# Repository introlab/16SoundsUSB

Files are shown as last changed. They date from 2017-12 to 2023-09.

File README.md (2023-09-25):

## 16SoundsUSB - 16 Synchronized Inputs USB (UAC2) Sound Card. 

## Authors
* Vincent-Philippe Rhéaume
* Dominic Létourneau
* Cédric Godin

We designed this sound card to work with our [ODAS](https://github.com/introlab/odas) sound source localization, tracking and separation library. You can also have a look at the [ODAS GUI](https://github.com/introlab/odas_web/) application. 

## 
* Please contact us if you need an already assembled [16SoundsUSB kit](https://github.com/introlab/16SoundsUSB/wiki/Kits).

## Latest Release
* [16SoundsUSB REV 1.0](https://github.com/introlab/16SoundsUSB/releases/tag/rev1.0)
  * [16SoundsUSB_Schematic](https://github.com/introlab/16SoundsUSB/releases/download/rev1.0/16SoundsUSB_Schematic_REV_1_0.PDF)
  * [16SoundsUSB_PCB_Fab_Assembly](https://github.com/introlab/16SoundsUSB/releases/download/rev1.0/16SoundsUSB_PCB_Fab_Assembly_REV_1_0.zip)

## Features

* 16 Synchronized Differential Inputs :
  * 2 x Cirrus Logic CS5368 high quality ADC (16 channels) 
* 4 Synchronized Single Ended Outputs :
  * Cirrus Logic CS4384 high quality DAC (4/8 channels used)
  * 2 Analog stereo outputs - 3.5 mm jack output format, 600Ω source impedance 
* Low-Jitter Master Clock :
  * Cirrus Logic CS2100 clock generator and clock multiplier/jitter-reduced clock frequency synthesizer 
* XTAG programming port
* Expansion header :
  * I2C-SDA, I2C-SCL, GPIO, GND, 5.6V (output of boost switching pre-regulator)
* Supported Sampling Rates :
  * 8kHz, 11.025kHz, 16kHz, 22.050kHz, 32kHz, 44.1 kHz, 48 kHz, 88.2kHz, 96 kHz
* Power :
  * USB Powered or
  * External 5V power supply
  * Measured current draw at 5V input for standard firmware: 600mA
* Supported Operating Systems :
  * Mac OSX, Linux, Windows 10 (UAC2 not working yet)
* Hand assembly is possible :
  * Mostly TQFP, SOIC packages on-board. Solder paste and heat gun recommended for 2 DFN-6 packages. 

## Pictures

16SoundsUSB Top
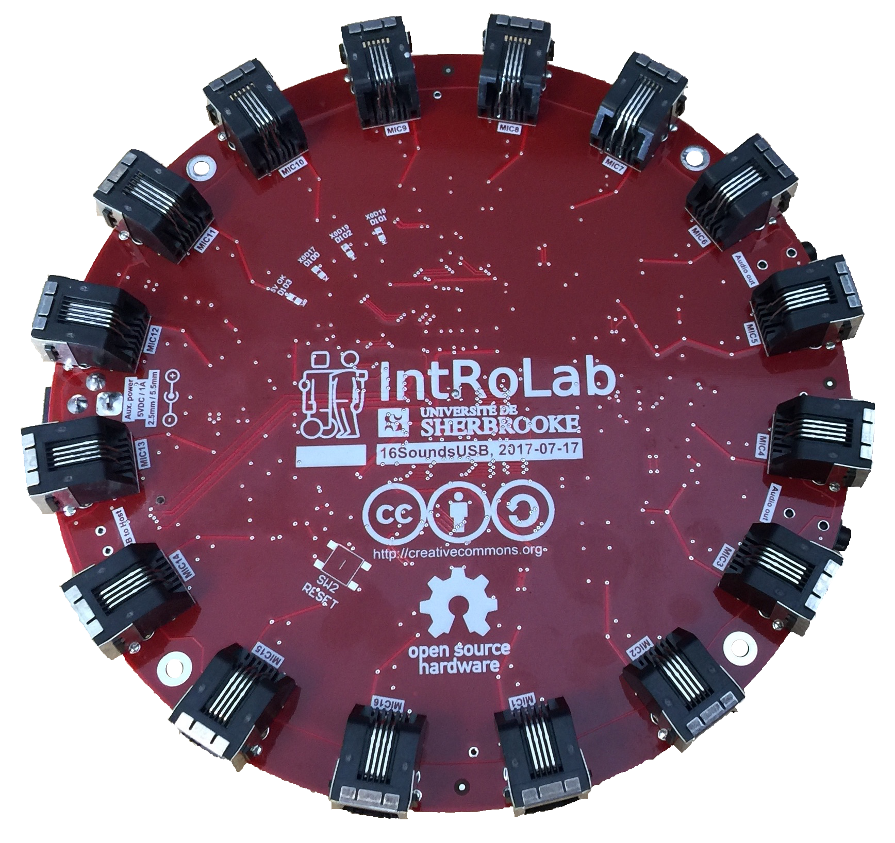
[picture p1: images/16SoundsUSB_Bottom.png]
16SoundsUSB Bottom


## Regulatory Compliance
Please read the [Regulatory Compliance Wiki Page](https://github.com/introlab/16SoundsUSB/wiki/Regulatory-Compliance).

## License

[Creative Commons Attribution Share Alike 4.0](https://github.com/introlab/16SoundsUSB/blob/master/LICENSE.txt)

## Microphones

[Compatible Electret and MEMS microphones](https://github.com/introlab/xSoundsMicrophones)

## Acknowledgements
The design is based on the [XMOS xCORE-200 Multichannel Audio Platform](https://www.xmos.com/support/boards?product=18334). This project is supported by [IntRoLab - Intelligent / Interactive / Integrated / Interdisciplinary Robot Lab](https://introlab.3it.usherbrooke.ca/), Sherbrooke, Québec, Canada.

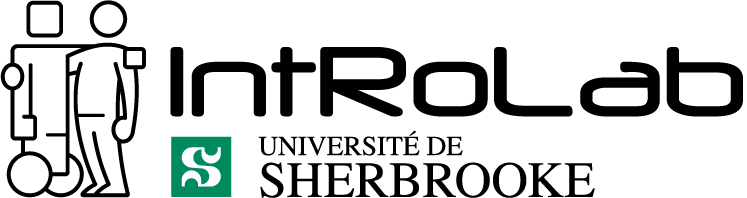
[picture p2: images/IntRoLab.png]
IntRoLab


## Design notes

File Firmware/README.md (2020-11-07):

# Flashing the firmware

## OSX

1. Load environment variables (your xTIMEcomposer version may vary)
* source /Applications/XMOS_xTIMEcomposer_Community_14.2.3/SetEnv.sh

2. Flash with xflash (your xTIMEcomposer version may vary)
* /Applications/XMOS_xTIMEcomposer_Community_14.2.3/bin/xflash <Firmware .xe file>

# Building the firmware

[You can get the code by agreeing to the licence on the XMOS site](https://www.xmos.ai/download/sw_usb_audio-[sw](6.15.2).zip) and make few changes to the sw_usb_audio-[sw]_6.15.2 reference firmware. Diff files from version 6.15.2 are provided in the [app_usb_aud_xk_216_mc](app_usb_aud_xk_216_mc) directory for your convenience. Sample rate support from 16kHz to 96kHz is included in the patch.

# Regulatory Compliance

Université de Sherbrooke provides 16SoundsUSB development board under the following conditions:

* 16SoundsUSB is intended for use for ENGINEERING DEVELOPMENT, DEMONSTRATION, OR EVALUATION PURPOSES ONLY and is not considered by Université de Sherbrooke to be a finished end-product fit for general consumer use.
* The 16SoundsUSB board generates, uses, and can radiate radio frequency energy and has not been tested for compliance with the limits of computing devices pursuant to part 15 of FCC rules, which are designed to provide reasonable protection against radio frequency interference. Operation of this equipment in other environments may cause interference with radio communications, in which case the user at his own expense will be required to take whatever measures may be required to correct this interference.
* Persons handling the product(s) must have electronics training and observe good engineering practice standards. As such, the goods being provided are not intended to be complete in terms of required design-,marketing-, and/or manufacturing-related protective considerations, including product safety and environmental measures typically found in end products that incorporate such semiconductor components or circuit boards. This evaluation board/kit does not fall within the scope of the European Union directives regarding electromagnetic compatibility, restricted substances (RoHS), recycling (WEEE), FCC, CE or UL, and therefore may not meet the technical requirements of these directives or other related directives.
* The user assumes all responsibility and liability for proper and safe handling of the goods. Further, the user indemnifies Université de Sherbrooke from all claims arising from the handling or use of the goods. Due to the open construction of the product, it is the user’s responsibility to take any and all appropriate precautions with regard to electrostatic discharge. NEITHER PARTY SHALL BE LIABLE TO THE OTHER FOR ANY INDIRECT, SPECIAL, INCIDENTAL, OR CONSEQUENTIAL DAMAGES. Université de Sherbrooke currently deals with a variety of customers for products, and therefore our arrangement with the user is not exclusive.
* Université de Sherbrooke assumes no liability for applications assistance, customer product design, software performance, or infringement of patents or services described herein.

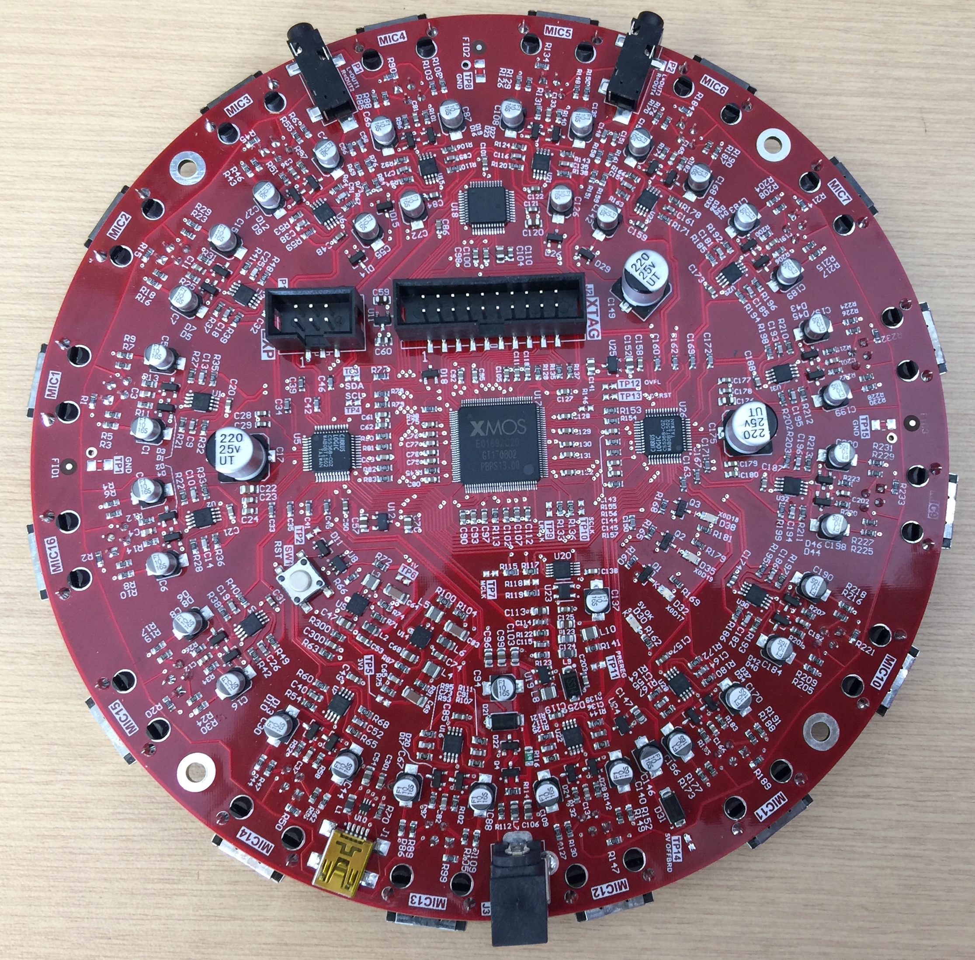
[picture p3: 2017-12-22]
images/16SoundsUSB_Top.jpg

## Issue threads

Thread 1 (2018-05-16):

Where can I purchase one of 16SoundsUSB?

jamesshao8, 2018-05-16:
This is probably rather an enquiry than an issue. I recently tried odas/odas_web with respeaker mic array v1.0 and v2.0. I am quite impressed by your project.

I want to improve the angle of separation, so that I can distinguish 2 sources in closer angles. I believe this 16 array would produce better result. So could you direct me some place that I can buy this 16 channel device?

Thanks.

doumdi, 2018-06-05:
Please email Prof. [François Michaud](mailto:francois.michaud@usherbrooke.ca) for a quote.

Thanks!

Closed 2018-07-16.

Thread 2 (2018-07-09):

microphone RJ45

jamesshao8, 2018-07-09:
Hello there,

I made one of this 16SoundsUSB according to your design files. I found there is actually no microphone on board, instead there are 16 RJ45 sockets.

According to the schematics, there are already on board input amplifiers, so what I need is some analog microphone units, and connect their outputs to each RJ45 port 2 and 4, right?

Do you have some suggestion about the microphone model/brand?

Thank you!

Regards,
Shao

qinyunchuan, 2018-07-15:
I think you should attach a ECM to the RJ45 connector.

jamesshao8, 2018-07-15:
It's actually RJ11, I found the design file of MIC-RJ11 board from 8SoundsUSB project. I think they can be used in this 16SoundsUSB project as well. So I am trying to make them locally.  Right now the I am working on how to download firmware to this board. What is ECM anyway? A type of microphone? I do have plan to customize the MIC board with better microphone for higher sensitivity.

doumdi, 2018-07-16:
Please have a look at the microphone design here : https://github.com/introlab/xSoundsMicrophones. We have electret design and MEMS design available.

doumdi, 2018-07-16:
Please note :  We use RJ11 connectors and cables in a custom configuration, allowing differential signals and power supply to our own microphone design. It is not compatible with any external 3.5mm adapter and microphone. We made this choice to make the system robust to noise, compact and easy to install. Everything is powered by the sound card, using USB 2.0.

jamesshao8, 2018-07-16:
Nice! Will take a look at these microphone designs.

jamesshao8, 2018-08-09:
Sorry, I was wrong about the sensitivity, mems with -38dB sensitivity should be better than the electret one with -44dB sensitivity. But which pre-amplification is better is still unknown to me. On electret design I have measured the real max gain is 20 times. Will try the mems one. I might also put those amplifiers in series and see how they work together.

vrheaume, 2018-08-09:
Hello James,

Our MEMS microphone board design is more recent and was designed to go along with our 16SoundsUSB. The electret microphone board design dates back to when the 8SoundsUSB was designed.

The gain values for both microphones were set in a very subjective / arbitrary manner. We had 2 concerns: we don't want too much gain to saturate the signal chain, yet we want enough gain to be able to hear properly when speaking from a few meters away.

Overall, we like the new microphones better with the 16SoundsUSB than we liked the older microphones with the 8SoundsUSB. However, we haven't done apples-to-apples comparison on the two microphone designs.

The MEMS microphone has better sensitivity (by 6dB) and better SNR (by 2-4dB), according to its specification (but I'm not sure we can really compare the specs since they're from different manufacturers, thus maybe different test conditions). We also experienced much, much less signal degradation coming from electromagnetic interference with the MEMS microphone (which we noticed recently when using the electret microphones a few inches away from a wifi router). The VM1000 MEMS microphone is supposedly waterproof and dustproof, features we haven't explored in-depth yet.

It is possible to change one resistor to adjust the gain on the electret microphone board, should you find it desirable. Let me know if you need help with this.

jamesshao8, 2018-08-10:
Thank your for your explanation.

I will try to make the mems one locally and compare them with the electret one. I noticed in the mems design R7/R6=10 is the gain, and I replaced R7 to 100k resistor, hoping to get higher gain. I have also bought some mics from knowles. One of them has -18dB sensitivity and 63dB SNR, another one has -40dB sensitivity and 70dB SNR. I am worried about saturating the ADC as well, so I am not sure choosing a mic with higher sensitivity or using higher gain in amplifier would guarantee I can hear sounds for longer distance, but I think higher SNR is always better.

vrheaume, 2018-08-10:
In case you haven't noticed, you should be aware that soldering the MEMS microphone is not trivial. The trick I use is to put solder on the PCB pads, then place the microphone with the tweezers, then use the hot air gun to reflow the solder. The MEMS microphone will self-align with the pads as the solder reflows, and then I give it a small push downward with the tweezer to make sure it is flat against the board.

If you go intend to increase the gain, you might want to make sure the opamp's gain-bandwidth specification is respected...

Keep us updated with the results of your experimenting!

jamesshao8, 2018-08-10:
We have a partnership with a local PCB/SMT factory. We usually ask them to do small volume prototyping. I think they are able to solder this mems microphones. But for knowles mics, I will have to solder them by myself, connecting them with some wires, so that I can put into my bread board and do the experiments.

We would love to contribute to this interesting project. So sure we will update our result.

jamesshao8, 2018-08-25:
Hello @vrheaume,

I have tried the mems mics these days. They are receiving sound in longer distance than electret ones indeed. And my own modification of the resistor increased the distance even further. But the distance is still not enough for me. And in long distance, I can't see obvious beamforming effect as I can in short distance.

Also I am wondering why a basic op-amp is used in the mems design instead of a specialized audio amplification chip in the electret? If I some how connect the mems mic to the amplification chip in electret design, will the distance be even longer? Thanks.

vrheaume, 2018-08-25:
Hello @jamesshao8,

Regarding the microphone distance: I have no precise recommendation for this, but here are a few thoughts:

- Perhaps you could get a few dB of gain with enclosure design.
- What is the maximum gain you experimented with? Perhaps we could try with higher gain still. Perhaps this would require another amplifier due to gain-bandwidth product limitation, perhaps it would require modifications on the microphone PCB design.
- Are you getting clean signals when you amplify more? Does it start getting noisy? If so perhaps we could find a lower-noise opamp (would cost a little bit more; perhaps something like the [OPA1662](http://www.ti.com/lit/ds/symlink/opa1662.pdf)).
- Perhaps we could shop around specifically for microphones that are intended by the manufacturer for "far-field use"; for example [this one](https://www.invensense.com/news-media/invensense-introduces-industrys-first-74-db-snr-analog-mems-microphone-enabling-far-field-audio-capture/).

Regarding the choice of using an opamp instead of the TS472 amplifier: I chose to do it this way because, in general, I try to use parts which have several compatible alternatives, so that we avoid sourcing problems. The opamp package is standard, you can find drop-in replacements from several manufacturers, and models with different specs (power consumption, THD, gain-bandwidth product, etc), which isn't the case for the TS472.

I do not tend to think you'll see much difference by using the TS472 instead of the amplifier that's already on the MEMS microphone board. That would be an interesting thing to try out; let us know if you do.

vrheaume, 2018-09-05:
Yes, an enclosure/case _could_ help a little bit. I am no acoustics expert, it seems hard to tell how much improvement you could get, but I would think on the order of 1dB perhaps.

Regarding the electronic gain: you could go about 6-10dB more, with just a slightly better opamp (such as MCP6L92) and changing R7; going above this might require a new circuit with two stages of amplification.

However, when you increase the gain (either mechanically by enclosure design, or electronically), the tradeoff is that you'll get saturation faster. "No free lunch!"

Perhaps an AGC (automatic gain control) function (either fully-analog, or a programmable amplifier controlled by real-time processing firmware), in addition to the amplifier, should be considered. It would involve some hardware development however. Here's an [application note on the subject of AGC](http://www.onsemi.com/pub/Collateral/AN-6603.pdf.pdf).

jamesshao8, 2018-09-05:
Hello @vrheaume ,

I just tested the 16SoundsUSB and mems mic with my own modification at R7 in a silent lab (No reflection of sound, and no noise from outside the room). We found there is actually very little noise left on the sound sources figure ( which means there isn't much background noise from the circuit). We can hear clearly human voice from a distance of 8 meters. So I think the sensitivity of mic and gain of op-amp is enough. Our main problem is with the beamforming algorithm. Also if we could extend 16SoundsUSB to a 64 channel device, it should have narrower pattern with high gain. But we will always try with high SNR mic and better op-amp. Since the modification of the main boards is too hard for us.

doumdi, 2020-08-19:
@jamesshao8 @vrheaume. There is a limitation with USB2 with the number of channels we can transmit over endpoints. 16 in is close to the maximum @ 96kHz.

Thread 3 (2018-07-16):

Please tell us what you do with 16SoundsUSB

doumdi, 2018-07-16:
We are curious to know how and where you use the 16SoundsUSB device. Please let us know!

jamesshao8, 2018-07-16:
I am originally from the radio world. Always wanted to study DOA and beamforming algorithm which is used in smart antenna. But multi-channel radio equipment are usually very expensive and there aren't many existing projects to learn from. Recently I found respeaker v2.0 can be used with odas to do 3-dimensional DOA and even beamforming. Then I found this 16SoundsUSB hardware, which I think can provide better resolution since it has more channel.

I think combined with a camera, 16SoundsUSB and odas can be used as an acoustic camera. To see where sounds come from and identify them on real-time video. With beamforming in static mode, I can even choose which sound source I want to listen to, like a telescope for sound. But if put into practical use maybe I need to scale it up to 64 channel or 128 channel and use microphone with higher sensitivity. Will experiment with existing design first and maybe simply some tuning in parameters will do.

doumdi, 2018-07-17:
@jamesshao8, thanks for sharing this with us. The acoustic camera and "static" beamformer capabilities are on the TODO list for ODAS. Please contact @FrancoisGrondin for questions concerning those topics.

U0x0U, 2020-08-19:
Hi, I'm from a research institute in Taiwan, which is committed to sound-related research .
16SoundsUSB is awesome for microphone array, and we plan to make the circuit board first.
I would really appreciate it if you could kindly give us some advice and suggestions.

doumdi, 2020-08-19:
@U0x0U you can find all fab files here: https://github.com/introlab/16SoundsUSB/releases. I would suggest you register to XMOS to get the firmware first to make sure it fits your needs. Few modifications are needed but the design is based on the
[xCORE-200 multichannel audio platform](https://www.xmos.com/products/audio/kits). You will need to accept the license and download the sw_usb_audio-[sw]_6.15.2 firmware and use the app_usb_aud_xk_216_mc for starting.

blursj, 2020-11-04:
@doumdi Dear sir, I am debugging 16SoundUSB board made by myself, and would you please release your few modifications which are needed based on the xCORE-200 multichannel audio platform? I appreciate for your help. My email is: blursj@gmail.com

roboav8r, 2020-12-01:
@doumdi I plan on integrating the kit onto a mobile robot platform, then using it for real-time human-robot interaction & sound event recognition.

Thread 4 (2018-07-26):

Is 4-wire RJ11 cable NOT supported by the 16SoundsUSB?

TooSchoolForCool, 2018-07-26:
Hi there,

Our lab bought a 16SoundsUSB from your lab a few months ago.

But now, we are trying to replace the original cable with a shorter one since the original cable is too long.

We bought some RJ11 cables from Amazon, and [here](https://www.amazon.com/Telephone-Plugs-Conductor-inches-Silver/dp/B01LKLRGWW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) is the link. However, these Rj11 cables do not work at all...

I was wondering what kind of cable is support by the 16SoundsUSB, and where can I find some shorter alternative cables.

Looking for your response, and thanks in advance :).

PS: I also took a picture of our RJ11 cable and the original cable. The left one is the RJ11 bought from Amazon, and the right one is the original cable.

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

vrheaume, 2018-08-02:
Hello,

Two things:

1. The connector on the 16SoundsUSB card can physically connect both to 4-pin and 6-pin "RJ" connectors. If using 6-pin connector and cable, only the 4 center pins are actually used to carry signals. [Go to this website for additional information on RJ11 and RJ12](http://www.differencebetween.net/technology/difference-between-rj11-and-rj12/)

2. The problem you are experiencing with the Amazon-bought cable is probably that it is a "straight" cable instead of a "crossed" cable. In a straight cable, pin 1 goes to pin 1, 2 goes to 2, etc; in a crossed cable, pin 1 goes to pin 4, pin 2 goes to pin 3, etc. In our case, +5V is on pin 4 on the microphone whereas it is pin 1 on the sound card itself, so you need a crossed cable. [This is an example of a crossed cable you can buy](https://www.amazon.com/Kenable-RJ12-Cross-Cable-BLACK/dp/B0051FKFXQ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). The reason for deciding to use crossed cables instead of straight is lost in time.

You should be able to confirm that the cables you have in hand are straight (Amazon) and crossed (ours) either visually (looking at the wire colors at both ends of the cable) or with a multimeter. You could buy new cables, or buy your own [connectors](https://www.amazon.com/Monoprice-Round-Stranded-50-Piece-107315/dp/B005E2Y7JE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) and [crimp tool](https://www.amazon.com/TRENDnet-RJ-45-RJ-12-RJ-11-TC-CT68/dp/B0000AZK4G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), to recycle the cables you have in hand and allow you to make custom-length cables in the future.

I hope this helps you. Let me know if it does not. I will look over our documentation and add a note regarding the type of cable if it isn't clear already. I'm sorry you had this problem.

Vincent R

TooSchoolForCool, 2018-08-10:
Thank you so much, Vincent!!!

I double checked both sides of the wire, I then found out their difference. And yes, the original cable is "crossed", whereas the one I bought from Amazon is not.

Again, thank you so much :).

vrheaume, 2018-08-15:
I'm glad I could help you figure this out. Let us know if you have more questions!

(I'm closing this issue since it is resolved)

Closed 2018-08-15.

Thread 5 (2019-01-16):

I can not compile

Yarulik, 2019-01-16:
Hello dear!

Thank you for such an interesting project, I was pleased to collect it!)

I compiled 16SoundUSB, but I cannot compile the project by changing the files as described.
An unmodified example app_usb_aud_xk_216_mc is compiled.

Additional targets can be installed from the xTIMEcomposer Studio
using the "Install New Hardware ..." option.
xmake [1]: *** [.build_2i16o16xxxxx_tdm8 / src / extensions / gpio_access.c.pca.xml.decouple] Error 1
xmake: *** [analyze] Error 2

Can anyone share a compiled project or a binary that I could check. I am an enthusiast and learn programming.

Thank you in advance!

yarulik1986@gmail.com

doumdi, 2019-01-18:
Hello @Yarulik ,

Have you tried the procedure [here:](https://github.com/introlab/16SoundsUSB/tree/master/Firmware)
With the firmware available [here :](https://github.com/introlab/16SoundsUSB/releases)

If you try compiling from XMOS source, try removing the gpio part, it is not needed.

doumdi, 2019-01-18:
In our firmware everything in gpio_access.c is commented.

doumdi, 2019-01-18:
**1) Comment line in audiohw.xc**
//#include "gpio_access.h"

**2) Add those definitions **
```
//Modified
on tile[0] : out port p_gpio_reset = XS1_PORT_4E;
on tile[0] : out port p_gpio_leds = PORT_LEDS;

//Define the address of the codecs
#define CS5368_I2C_ADDR1      (0x4D)
#define CS5368_I2C_ADDR2      (0x4C)

//Also define write function  to both codecs
#define ADC_REGWRITE1(reg, val) {data[0] = val; i2c_shared_master_write_reg(r_i2c, CS5368_I2C_ADDR1, reg, data, 1);}

#define ADC_REGWRITE2(reg, val) {data[0] = val; i2c_shared_master_write_reg(r_i2c, CS5368_I2C_ADDR2, reg, data, 1);}

//make sure you reset both codecs with this call
p_gpio_reset <: 0x00;

//And remove reset with this
p_gpio_reset <: 0x0F;

//Also make sure you duplicate all write to both CS5368 and you will be good to go!

```

I hope this helps.

Yarulik, 2019-01-18:
Thanks for the help!

Yarulik, 2019-01-19:
I apologize in advance for machine translation!

Today I wanted to download a binary file that you gave me, but there were problems. I confused several components R77, R79, R98 during installation, put the capacitors. Because of this, the supervisor issued on TP2 2.46V. After installing the correct components, the voltage became 3.3V
 As far as I understand the RST should be LOW. And when resetting supervisors, issue a single HIGHT pulse for 140 ms and again LOW.
I have on RST (TP_2) HIGHT, while holding the button (SW1) LOW .....
The programmer works, the IDE shows it s / n, the diodes are shown.

Probably somewhere I was wrong again! I can not understand where. I would not want to burn the microcontroller, it was very difficult for me to get it.

voltage:
VDDIOR: 3.35V
VDD: 1.0V
RST_N: 3.3V
PLL_AVDD: 1.0V
OTP_VCC: 3.35V
PREREG: 5.65V
Crystal oscillator VCC: 3.3V
Я начал более подробное изучение документации и установленных сдвоенных диодов D11 "звонится только один диод", что странно. Я его поздно обнаружил и не успел поменять. Может ли это быть причиной HIGHT на RST?

Подскажите пожалуйста, что я ещё упустил????

Closed 2019-01-19.

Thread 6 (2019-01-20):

xrun: Cannot load image, XCore 0 is not enabled

Yarulik, 2019-01-20:
Hello!

I apologize in advance for machine translation!

Today I wanted to download a binary file that you gave me, but there were problems. I confused several components R77, R79, R98 during installation, put the capacitors. Because of this, the supervisor issued on TP2 2.46V. After installing the correct components, the voltage became 3.3V
As far as I understand the RST should be LOW. And when resetting supervisors, issue a single HIGHT pulse for 140 ms and again LOW.
I have on RST (TP_2) HIGHT, while holding the button (SW1) LOW .....
The programmer works, the IDE shows it s / n, the diodes are shown.

Probably somewhere I was wrong again! I can not understand where. I would not want to burn the microcontroller, it was very difficult for me to get it.

voltage:
VDDIOR: 3.35V
VDD: 1.0V
RST_N: 3.3V
PLL_AVDD: 1.0V
OTP_VCC: 3.35V
PREREG: 5.65V
Crystal oscillator VCC: 3.3V
Я начал более подробное изучение документации и установленных сдвоенных диодов D11 "звонится только один диод", что странно. Я его поздно обнаружил и не успел поменять. Может ли это быть причиной HIGHT на RST?

Подскажите пожалуйста, что я ещё упустил????

Yarulik, 2019-01-20:
hink/16SoundsUSB/Firmware/16SoundsUSB_Firmware_REV_1_0.xe
xrun: Cannot load image, XCore 0 is not enabled

think@think-ThinkPad-T470p:~/XMOS/xTIMEcomposer/Community_14.3.3$ xflash --list-devices

Available XMOS Devices
----------------------

  ID	Name			Adapter ID	Devices
  --	----			----------	-------
  0 	XMOS XTAG-3         	hNwmAqzA	O[0]

doumdi, 2019-01-22:
Maybe this will help : https://www.xmos.com/developer/support/knowledgebase/why-do-i-get-cannot-load-image-xcore-0-not-enabled

Closed 2020-08-19.

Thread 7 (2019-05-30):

Getting started - Interface configuration and flashing firmware

seanernestmurray, 2019-05-30:
Hello!

Our laboratory recently bought the 16soundsUSB. I'm running into trouble getting the board up and running in the ODAS Studio environment. This may be pretty basic, so please excuse the inexperience.

I've followed the installation (from source) and configuration procedures for ODAS and have added the TCP sockets required for local communication with ODAS Studio (in the sounds16USB.cfg file, zipped below). I've installed ODAS Studio and it starts up without any issue, and added the following paths in ODAS control:
/home/sean/odas/bin/odaslive
/home/sean/odas/config/odaslive/sounds16USB.cfg

At this point I'm not sure of the next step to take in order to get ODAS Studio running with the board.

In my .cfg file, I've specified a .raw input file named "raw_16mics.raw". Is this the correct interface for the 16soundsUBS or does the choice, eg soundcard, depend on the application? I can't seem to find any info for the interface configuration in the wiki.  In what cases do I need to flash firmware? There are instructions given for flashing firmware using OSX, but none for the operating system I'm currently using, Ubuntu 18.04.2 LTS.

[sounds16USB.zip](https://github.com/introlab/16SoundsUSB/files/3237813/sounds16USB.zip)

**UPDATE:**
I'm using Audacity to record audio from the board and then saving it as a .raw file to be accessed when running ODAS. Once I launch ODAS Studio the audio is registered on-screen, however I'd like to be able to write/read from a .raw file in real-time. Have you any suggestions of how to do this?

Thanks,
Sean

seanernestmurray, 2019-06-04:
I believe I figured out most of the issues listed above.

For real-time data, a soundcard interface may be specified in the 'raw' section of the .cfg file. This is outlined below - no firmware needs to be flashed for this.
```
raw:
{
    fS = 44100;
    hopSize = 512;
    nBits = 32;
    nChannels = 16;

    # Input with raw signal from microphones
    interface: {
        type = "soundcard";
        card = 2;
        device = 0;
    }
}
```
One small point to note is that in order to run ALSA with the board, the PC must not be registering the input as an active audio source - i.e. audio input from the board should be disabled in general settings before trying to access the audio data in ODAS. (This may be an obvious troubleshoot, but a speedbump nevertheless.)

doumdi, 2019-06-05:
@seanernestmurray. Happy you got the system working. You are right, there is no need to flash the sound card firmware. The procedure you found is for flashing the firmware the first time, when people build the PCB themselves. The best way to get started is with sample configurations. Here is one with 16 inputs : https://github.com/introlab/odas/blob/master/config/odaslive/azimut_oma.cfg

For ODAS questions, It would be better to fill issues here : https://github.com/introlab/odas/issues or here : https://github.com/introlab/odas_web

Depending on your Linux configuration and if 16SoundsUSB is your only sound card in the system, it is possible that the sound card was already opened by another process. Thanks for sharing this problem with us.

Regards,

Dominic

seanernestmurray, 2019-06-14:
Thanks Dominic!

Closed 2020-08-19.

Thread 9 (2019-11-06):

What is the adc pin output when no input channel is  connected for both TDM/I2S?

Utsav196, 2019-11-06:

doumdi, 2020-08-19:
@Utsav196, Not sure I understand your question. @vrheaume any idea?

SCWhite, 2020-08-20:
HI, this is a great project.
I'd like to know if this 16SoundsUSB board support I2S microphones
(e.g. SPH0645 ) it's a I2S MEMS Microphone.

If so how can I do this ?

vrheaume, 2020-08-20:
Hello @SCWhite,

No, 8SoundsUSB/16SoundsUSB are not adequate for "digital" microphones. Those weren't very popular back when we first started, so they weren't given much consideration; instead we went for "analog" microphones and ADCs (which hasn't been a bad choice! it works for our ManyEars sound localization project). Since then we have noticed the potential cost advantage of "digital" microphone (no expensive ADC! no signal conditioning!), but also the risk associated with it (high-frequency digital signals on a cable that we want to be inexpensive = potential EMI problems?). It is certainly something that we want to look into further, but haven't done it yet.

To go forward, I would tend to look into application notes and reference designs by XMOS. Such as [this one](https://www.xmos.com/download/xCORE-Microphone-Array-hardware-manual(2V0).pdf) which supports PDM microphones. Perhaps they have a similar development board/schematics/firmware for I2S microphones.

Let me know if you start something along those lines, and how we can help. What are the advantages of I2S microphones in your application?

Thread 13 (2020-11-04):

16SoundsUSB open source board debugging records and issues

blursj, 2020-11-04:
1、Hardware part
We obtained hardware design information and firmware information from the open source website https://github.com/introlab/16SoundsUSB. The first version produced five development boards that were exactly the same as the open source website (due to a procurement error, the main chip was soldered to XE216-512-TQ128, instead of XEF216-512-TQ128 in the BOM of the open source website), and purchased a piece of xTAG-v3 emulation programmer from Taobao, as shown in Figure 1 below:

Figure 1、16SoundsUSB xTAG-v3
Fixed the error of reverse polarity connection of D21 and D31, the 24MHz main clock U23 was soldered, the dual power strobe MOSFET Q4 was soldered, and the clock source selection resistors R118 and R146 were redundantly soldered. After several hardware errors, the system basically worked normally after power on Except that the entire system does not have QSPI FLASH (there is no inside or outside of the XMOS main control chip), is it possible to try to make the system work by downloading the firmware program inside the XMOS chip?
The system first uses an external 5V constant current source to supply power, and the power-on current of the system is about 0.0784A, as shown in Figure 2.

Figure 2. Voltage and current at first power-up
XMOS supply voltage 3.3V works normally, as shown in Figure 3

Figure 3. 3.3V voltage
XMOS supply voltage 1.0V works normally, as shown in Figure 4

Figure 4. 1.0V voltage
XMOS external 24MHz active crystal is working normally, as shown in Figure 5

Figure 5, 24MHz active crystal oscillator
2、Software part
Download the firmware 16SoundsUSB_Firmware_REV_1_0.xe from the open source website https://github.com/introlab/16SoundsUSB/releases/tag/rev1.0, and from https://github.com/introlab/16SoundsUSB/tree/master/Firmware Download the configuration file 16SoundsUSB.xn in the project.
On the lubuntu16.04.6 system, configure the xTIMEcomposer 14.4.1 of the XMOS development software (from the official website
https://www.xmos.ai/software-tool)xTIMEcomposer-Community_14-Linux64-Installer_Community_14.4.1.tgz, after solving the problem of square characters and xTAG-v3 access rights. The project can be compiled, simulated and downloaded firmware through XMOS development software.
The first step is to test our own engineering project. The startup procedure is as follows:

Import the project app_usb_aud_xk_216_mc, as shown in the figure

Change the configuration file in the XMOS official website reference board project app_usb_aud_xk_216_mc
/home/skd/workspace/app_usb_aud_xk_216_mc/src/core/xk-audio-216-mc.xn and open source
https://github.com/introlab/16SoundsUSB/tree/master/Firmware to download the configuration file 16SoundsUSB in the project. xn for comparison, because the XS2-UnA-512-FB236 configuration is used in the XMOS official website configuration file, and our development board uses XE216-512-TQ128 (without FLASH). So replace the left side of the figure below with the content on the right

becomes

Also modified
/home/skd/workspace/app_usb_aud_xk_216_mc/src/core/customdefines.h

/* Enable/Disable SPDIF output - Default is S/PDIF on */
#ifndef SPDIF_TX
#define SPDIF_TX	       1
#endif
becomes
/* Enable/Disable SPDIF output - Default is S/PDIF on */
#ifndef SPDIF_TX
#define SPDIF_TX	       0
#endif
and
/* Number of IS2 chans to DAC..*/
#ifndef I2S_CHANS_DAC
#define I2S_CHANS_DAC      (8)
#endif

/* Number of I2S chans from ADC */
#ifndef I2S_CHANS_ADC
#define I2S_CHANS_ADC      (8)
#endif
becomes
/* Number of IS2 chans to DAC..*/
#ifndef I2S_CHANS_DAC
#define I2S_CHANS_DAC      (4)
#endif

/* Number of I2S chans from ADC */
#ifndef I2S_CHANS_ADC
#define I2S_CHANS_ADC      (8)
#endif
The compilation result is as shown in the figure below, and the binary executable file is obtained: app_usb_aud_xk_216_mc_1i2o2xxxxxx.xe

Ability to perform online simulation and operation in the IDE development environment

Online simulation selection simulator

The program is running normally, as shown in the figure below, where the second light from right to left on xTAG-v3 keeps flickering.

At this time, the system current increases to 0.411A, as shown in the figure below.

The ADC_RST_N level changes to 3.3V high level, and the quantity TP13 is shown in the figure below. It should be the ADC starting to work.

MCLK_AUDIO becomes 1.152MHz, and the right side of R146 is shown in the figure below, that is, the clock signal to ADC works normally.

Measured the 4 data ports ADC2_SDOUT4 of the second ADC chip, that is, R83 pin has data as shown below.

The 4 data pins related to the first ADC chip have no signals.
Insert the USB cable at this time, the current drops to about 0.10A, but after a while it returns to about 0.42A.
lsusb Check the newly added device and show Bus 001 Device 009: ID 20b1:0009 XMOS Ltd

Open the Audacity recording software, the xCORE USB Audio 2.0 device can be recognized, as shown below

But the multi-channel option is only 2, and 10 does not appear. As shown below:

The two channels seem to be able to record, but the front MIC is not connected for test verification.
The second step is to test the open source firmware --
16SoundsUSB_Firmware_REV_1_0.xe. First unplug the USB cable. Configure the open source firmware in the operating options of xTIMEcomposer, as shown in the figure below:

Then click the Run button in the lower right corner, the open source firmware is downloaded to the board through xTAG-v3 and starts to run, the xTAG light flashes, and the system current becomes 0.355A, as shown in the figure below.

At this time, ADC_RST_N is high, MCLK_AUDIO has a signal of 1.152MHz, and at this time, each of the four data lines of ADC1 and ADC2 has data signals.
But unlike the compiled firmware, after plugging in the USB, the current drops to 0.1044A, ADC_RST_N becomes low level, MCLK_AUDIO clock signal disappears, and the 4 data lines of ADC1 and ADC2 become low level.

When the USB is plugged in, the two pins TP4 (SCL) and TP3 (SDA) of the I2C bus have signals, as shown in the figure below
TP3(SDA)

TP4(SCL)

At this time, lsusb checks the newly added device and shows Bus 001 Device 015: ID 20b1:0008 XMOS Ltd, as shown in the figure below

Open the Audacity recording software, the 16SoundsUSB Audio 2.0 device can be recognized, as shown below

And there are 16 channels in multi-channel selection,

But when I started recording, I couldn't turn on the device, as shown in the figure below.

At this time, unplug the USB line and plug in the USB line, lsusb will not appear new XMOS USB Audio devices.

3、summary of issues
a. How to correctly modify the rest of the files except .xn in the project app_usb_aud_xk_216_mc to drive ADC1, ADC2 and DAC1 correctly? Can open source projects provide complete source code? Including how to modify files such as customdefines.h and audiohw.xc.
b. Are there other problems with the hardware? In the absence of external QSPI-FLASH and the internal FLASH of the chip, can the firmware be downloaded to the XMOS on-chip RAM through xTAG to run normally, and at the same time, it can support repeated USB cable plugging and unplugging and correctly identify the USB Audio Device, and it can be used Does Audacity record 16 channels?
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
blursj, 2020-11-11:
Very strange.
I changed code as below:
1.
void AudioHwInit(chanend ?c_codec)
{
#if !(defined(SPDIF_RX) || defined(ADAT_RX)) && defined(USE_FRACTIONAL_N)
    /* Output a fixed sync clock to the pll */
 // configure_clock_rate(clk_pll_sync,100,100/(PLL_SYNC_FREQ/1000000));
    configure_clock_rate(clk_pll_sync, 100, 100);//100000000/PLL_SYNC_FREQ);
    configure_port_clock_output(p_pll_clk, clk_pll_sync);
    start_clock(clk_pll_sync);
#endif
2.
#if !(defined(SPDIF_RX) || defined(ADAT_RX))
/* Choose a frequency the xcore can easily generate internally */
//#define PLL_SYNC_FREQ 1000000
#define PLL_SYNC_FREQ 94000//1000000    //94000 for no driver,86000 no use
#else
#define PLL_SYNC_FREQ 300
#endif

Then I get a frequency approximately 12.288MHz which is hardly measured by
an oscilloscope. But I don't know if it is correct?
I can listen music from line out(DAC), There seems to be a little noise, I
don’t know if the drive capacity of MCLK is not enough or the frequency is
not accurate enough.

I don’t know if the CS2100-CP-CZZ I bought is correct. I think all the
problems with my board are on the CS2100 chip. It seems that the I2C
configuration is not working properly?

Dominic Létourneau <notifications@github.com> 于2020年11月11日周三 上午6:08写道：

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

doumdi, 2020-11-11:
@vrheaume do you have an idea what could be the problem?

blursj, 2020-11-11:
CS2100 chipset, but I don't know why?

Dominic Létourneau <notifications@github.com> 于2020年11月11日周三 下午9:12写道：

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

vrheaume, 2020-11-12:
Hello,

For some reason I can't see the figures in your post, so forgive me if I ask questions that seem redundant.

How do you measure the power consumption? Is it done with the XTAG somehow, or with an external power supply connected to the DC input barrel connector (5V)?

I don't think the LEDs should blink like you describe, so even before looking closely at the PLL chip, I would tend to take a step back.

If I understand correctly, the 16SoundsUSB card is powered by the XTAG, until you initially plug in the USB, and then goes back by itself to being supplied by the XTAG? Perhaps there is a glitch occuring when the power switches over? @doumdi have we done this before?

The 16SoundsUSB can draw quite a bit of power from the USB port, in some cases more than the USB 2.0 typical max of 500mA (depending on ADC frequencies, USB cable losses). It may be farfetched and we haven't actually experienced this, but I could see a computer failing to deliver this much power properly over the USB, which could generate dips in the power supplies, which could lead to initialization problems on the board...

In order to set this hypothesis aside, I would tend to suggest that you try powering the board from a lab power supply or a wall wart power supply (5V, >1A) connected to the DC input barrel connector, before we investigate further.

If you have a good oscilloscope I would also recommend to measure the 3,3V supply before-and-after connecting the USB port to see if there is a short transient there.

We could verify the output of the CS2100 on R117 or R65 after initialization on our boards, like you said, to verify if we obtain the same frequency as you do. It might take a few days.

Vincent

blursj, 2020-11-12:
Hi vrheaume,
Sorry that I don't know how to post figures in forum, I just attached my
debug document with figures in email. You can check it and help me.
My question focuses on the output frequency of the CS2100 which is
MCLK_AUDIO, the very important frequency.
It is 1.152MHz running 16SoundsUSB_Firmware_REV_1_0.xe which is you
provided.
After I modified some code unconventionally, it became close to 12.288MHz.
I want to know why?

Thank you all guys,
best regards,
shijian

vrheaume <notifications@github.com> 于2020年11月12日周四 下午12:35写道：

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

doumdi, 2020-11-12:
@blursj can you verify the clock signal (generated by the XMOS chip) you get at PLL_SYNC?

doumdi, 2020-11-12:
Also make sure R118 is NI.

blursj, 2020-11-15:
sorry too late to reply, make sure that R118 and R146 is NI. and get
PLL_SYNC is 1MHz. But still fail to open device using opensource firmware.
shijian

Dominic Létourneau <notifications@github.com> 于2020年11月13日周五 上午1:09写道：

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

blursj, 2020-11-15:
I will test new design hardware a few days later. I redesigned clock
circuit refer to XMOS original design and check what is the problem.

Dominic Létourneau <notifications@github.com> 于2020年11月13日周五 上午1:09写道：

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

SCWhite, 2020-12-30:
HI @doumdi
I'm a little confused, having the same problem
where should we do this change,  in the "customdefines.h" file?
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

Thanks for your help

doumdi, 2020-12-30:
@SCWhite Make the change to the file : module_usb_audio/main.xc.

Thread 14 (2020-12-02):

Clarification on firmware patching/flashing

roboav8r, 2020-12-02:
Hi all,
I just got my hardware kit, but unfortunately I am not sure how to flash the firmware properly. I understand the concept, but am not sure of which **specific** commands to run to apply the patch & flash the firmware onto the kit.

My OS:
- Ubuntu 20.04

From XMOS, I have:
- [sw_usb_audio-[sw]_6.15.2](https://www.xmos.ai/download/sw_usb_audio-%5Bsw%5D(6.15.2).zip)
- [xTIMEcomposer 14.4.1](https://www.xmos.ai/file/xtimecomposer-community_14_4_1-linux64-installer?version=latest)

From this repository, I have:
- [16SoundsUSB_Firmware_REV_1_0.xe](https://github.com/introlab/16SoundsUSB/releases)
- The firmware [patch](https://github.com/introlab/16SoundsUSB/tree/master/Firmware/app_usb_aud_xk_216_mc)

And so far, I have done the following:
- Set up udevrules for the device, as in section 2 [here](https://www.xmos.ai/download/Enable-USB-drivers-on-Linux(X2612A).pdf). When I connect it to a USB2.0 port, `lsusb` shows `ID 20b1:0008 XMOS Ltd 16SoundsUSB Audio 2.0`.
- Sourced the shell script `source .../xTIMEcomposer/Community_14.4.1/SetEnv.sh`
- `.../xTIMEcomposer/Community_14.4.1/bin/xflash .../16SoundsUSB_Firmware_REV_1_0.xe`

The last command results in the following error:
`Error: F03136 No devices attached - Cannot run the enquirer until a device is found`

Beyond this, I'm not sure which commands to run or files to edit. Could anyone provide some more specific information about how to apply the patch and flash it to the kit?

Thanks!

doumdi, 2020-12-07:
Hello John,

Could you first tell me why you need to flash the firmware since it was already done when you purchased the kit?

doumdi, 2020-12-07:
The device requires no driver and Linux will recognize it as an USB sound card. You can use Audacity or any other audio tool compatible with ALSA for record/playback to the device.

roboav8r, 2020-12-08:
Thanks @doumdi! I didn't realize the kit had the firmware flashed already.

Closed 2020-12-08.

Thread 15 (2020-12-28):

Error when uploading the firmware

SCWhite, 2020-12-28:
HI,

I've been having a problem uploading the firmware to the 16SoundsUSB board using XTAG3 adapter.

OS:          Ubuntu 16.04
Version:   xTIMEcomposer  Community_14.2.3
Board:     16SoundsUSB Rev1.0
Error message:

> xrun: Cannot load image, XCore 0 is not enabled

I managed to see the adapter and device by "xflash -l"
so I think my environment is installed correctly .
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

According to other issue (#6) this might cause by "Thermal pad not connect to GND"
but I checked with my multimeter it seems connected properly.

Is there another way to resolve this error ?

Any help would be greatly appreciated

Thank you

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

SCWhite, 2020-12-29:
Little update, I'm trying flashing on Windows, and I get some different error message.

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

I'm using the "16SoundsUSB_Firmware_REV_1_0.xe" file

SCWhite, 2020-12-29:
Update, issue has been solved
this is cause by hardware error, U23 is misplaced

after track down this problem, and fix it with a hot air gun
firmware can be successfully upload to board (on linux)

If possible, can anyone recheck if U23 is correct in the released file?
"16SoundsUSB_PCB_Fab_Assembly_REV_1_0.zip"
there is also a chance may cause by PCB factory.

Closed 2020-12-29.

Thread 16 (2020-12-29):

About using 16SoundsUSB

SCWhite, 2020-12-29:
I finally get the firmware uploaded (at least I think I do)

by following the instruction from "16SoundsUSB/Firmware/README.md"
I flashed "16SoundsUSB_Firmware_REV_1_0.xe " on my board

here comes the question, my Linux do not recognize 16SoundsUSB as a sound card
and I can't see the device by using "lsusb" or "audacity"

how do I know if this is done correctly? It should be recognize as a sound card, right?

also, after plugin to the computer, 4 leds keep lighting up
this does not match the description from #13

>by @blursj
> when the usb power supply is plugged in, LEDs 1~3 blink 4 times and then go out.

any advice or suggestions?

Thank you very much.

I'm using:
OS: Ubuntu 16.04
Version: xTIMEcomposer Community_14.2.3
Board: 16SoundsUSB Rev1.0

and the board looks like this:

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

doumdi, 2020-12-30:
@SCWhite Try to upload the code from XTimeComposer using the XTAG adapter and verify if you get error messages when USB starts to connect.

doumdi, 2020-12-30:
@SCWhite, The first thing I would verify using a scope is the I2C communication to CS2100-CP-CZZ (Clock generator), CS4384 (DAC), CS5367 (ADC x2). Check for NACKs, transmission errors, etc. Make sure the two CS5367s are on different I2C addresses (PIN 37, 38). The firmware will fail (assert) if I2C communication does not work and restart. The codecs are configured after USB is initialized by Linux usb_audio driver and sets the sampling rate. So you need to plug USB to the computer for testing.

SCWhite, 2020-12-31:
@doumdi  Thank you very much.
 I'll test them immediately.

SCWhite, 2020-12-31:
OK, I got it working on my device. It can be recognized as a usb device.
Thanks for pointing out to check I2C, you are the best.
(but the led is still strange though)

Another question, is this change from issue #13 necessary for the project ?
file: "audiohw.xc"

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

if so, I can sum up and whrite a few procedure/instruction for using this project.

Thanks again

doumdi, 2020-12-31:
@SCWhite. No, those changes should not be done in audiohw.xc and were done to test clock signals. I suggest you add information to a new markup file (ASSEMBLY_NOTES.md?) and make a pull request.

doumdi, 2020-12-31:
@SCWhite, I have also added the diff file in the master branch for main.xc in the usb_audio_module.

jiangjiang4563, 2023-05-10:
hi, sir, did you get it to work properly and do you know if a computer supports two such devices at the same time

SCWhite, 2023-05-10:
@jiangjiang4563  Yes, I can confirm this project works properly (even magnificently)
and a normal computer (in my case linux and windows) are able to support more than one device at the same time.

jiangjiang4563, 2023-05-10:
> @jiangjiang4563 Yes, I can confirm this project works properly (even magnificently) and a normal computer (in my case linux and windows) are able to support more than one device at the same time.

jiangjiang4563, 2023-05-10:
@SCWhite Thank you for your prompt reply. It will keep me engaged in this work  :-)

Closed 2021-01-04.

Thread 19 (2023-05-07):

Inquiry about compatibility of multiple microphone arrays

jiangjiang4563, 2023-05-07:
Hello, sir,  I wonder if I can connect two or more microphone arrays to one computer and record sound at the same time.

doumdi, 2023-05-10:
The problem you might encounter is that each device has its own clock and one sound card is not synchronized with the other. Sample alignement must then be done by software. For each sound card (16 inputs), you are 100% sure every channel is synchronized though.

jiangjiang4563, 2023-05-11:
@doumdi Thank you for your constructive suggestions, I will try to figure it out.

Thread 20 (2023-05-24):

firmware load problems

andryvinogradov, 2023-05-24:
Hello, nead help(((
 I soldered board
XEF216-512-TQ128-C20 no longer manufactured , i used XEF216-512-TQ128-C20A
ASDMB-24.000MHZ-LC-T no in stock (((,i used FJ2400011 , it have identical parameters but its Crystal  not Mems , is it critical?

XTC TOOLS 15.2.1
Studio Community 14.4.1

TP6 0.98V
TP5 3.38V
TP2 3.38V when JTAG connected 2.74V

I have error when upload firmware:
"C:\Users\Rider>xflash D:\16SoundsUSB_Firmware_REV_1_0.xe
Tile 0 has not booted following write to TestMode register. Target device may be held in resetxrun: Cannot load image, XCore 0 is not enabled"

Xflash indicates that  chip is connected :
" ID    Name                    Adapter ID      Devices
  0     XMOS XTAG-3       KCSMOEJN        O[0]"

I soldered new board with new componetns, result is same
Processoe thermal pad is normal soldered , i used infrared reflow.
Ocsillator in change in randge 23.92-24.15 MHZ  could this be a problem?
A revision of processor can be a problem?
Thanks))))

https://github.com/introlab/16SoundsUSB/assets/15078619/3209aee4-48fd-486a-b931-3f44f7893cae
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

Closed 2023-09-03.

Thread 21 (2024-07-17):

Programmable only after desoldering resistor PLL R118

Yarulik, 2024-07-17:
**Hello dears!**
I finally got around to getting this wonderful microphone out of my long drawer.
 I checked everything many times, all the well-known recommendations, and found out that resistor **R118** blocks XMOS programming.
Having unsoldered it, I was able to flash **16SoundsUSB_Firmware_REV_1_0.xe**, the equipment appeared in the system, but the microphones did not work.
If you solder **R118** (0R), the controller freezes and does not initialize. The oscillator produces exactly **24 MHz**. Я использую **XEF216-512-TQ128-C20**
**15th xflash:**
```
xflash 16SoundsUSB_Firmware_REV_1_0.xe
Site 0 has finished successfully.
```
**14th xflash:**
```
Warning: F03098 Factory image and boot loader cannot be write-protected on flash device on node 0
xflash: Warning: F03148 --quad-spi-clock not given, using default 15.62MHz
xflash: Warning: F03149 QE_REGISTER and/or QE_BIT locations not found in XN file for this flash device. Using default flash_qe_location_status_reg_0 and flash_qe_bit_6.
Warning: F03150 The use of libquadflash will be deprecated from XFLASH in xTIMEcomposer 15.0.0.
Please add the PageSize, SectorSize and NumPages attributes to your External Device definitions in your target XN file to enable the use of lib_flash.
Site 0 has finished successfully.
```
What could be my mistake?

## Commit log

2018-01-09 Initial commit/release. PCB design was assembled and tested.
    [16SoundsUSB.PrjPCB, ADC.SchDoc, AudioInputs_8.SchDoc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]
2018-01-22 Removed unnecessary files and renamed folder
    [16SoundsUSB.PrjPCB, ADC.SchDoc, AudioInputs_8.SchDoc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]
2018-01-23 Added Show Partnumber on U20 (PLL)
    [16SoundsUSB.PrjPCB, Clock.SchDoc]
2018-01-25 minor modifications to README file -added current draw -added more precision to the hand assembly information (package types)
2018-01-25 Added mfg+supplier part numbers for resistors and capacitors.
    [16SoundsUSB.PrjPCB, ADC.SchDoc, Clock.SchDoc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]
2018-01-25 added revision number on PCB
    [16SoundsUSB.PrjPCB, TopLevel.SchDoc]
2018-01-25 renamed PCB file
2018-06-04 Relative paths for automatic outputs (OutputSettings.OutJob)
    [16SoundsUSB.PrjPCB]
